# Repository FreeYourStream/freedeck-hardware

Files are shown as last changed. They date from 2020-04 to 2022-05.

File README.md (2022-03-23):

# FreeDeck

## Be careful when printing cases. PCB rev 1.1 - 1.3 has new dimensions. Most cases on thingiverse are still for rev 1.0!

The first cases for Rev 1.1 / 1.2 / 1.3 can be found in the wiki (See link below)

## This Repo contains all the stuff you need to build your own FreeDeck

- [Walkthrough and tutorial](https://youtu.be/-3Zw8hbpVq4) video from Adam Welch
- [Demo Video](https://www.youtube.com/watch?v=_TcliiU2K48) of my first prototype

### [Discord Community](https://discord.gg/sEt2Rrd)

## Description

The FreeDeck aims to be a Free/OpenSource replacement for Elgatos Streamdeck and similar.
It works by creating a config file with the FreeDeck [Configurator](https://fdconfig.freeyourstream.com/), loading it onto an SDCard and inserting it into the FreeDeck. You don't need to install any software and can use it across reboots on Windows, Linux and MacOS. This was my main reason behind this gadget.
This prototype is made from:

- Perfboard
- Arduino Pro Micro (32u4 16mhz 5v)
- 2x 4051 Multiplexer
- 6x ssd1306 OLEDs
- 6x 3x4x2mm SMD buttons
- SPI-SDcard Reader

The Arduino Code can be found [here](https://github.com/koriwi/freedeck-ino)

The Configurator Repo can be found [here](https://github.com/koriwi/freedeck-configurator)

A wiki on how to construct it can be found [here](https://github.com/FreeYourStream/freedeck-wiki/wiki)

Image of first FreeDeck Prototype

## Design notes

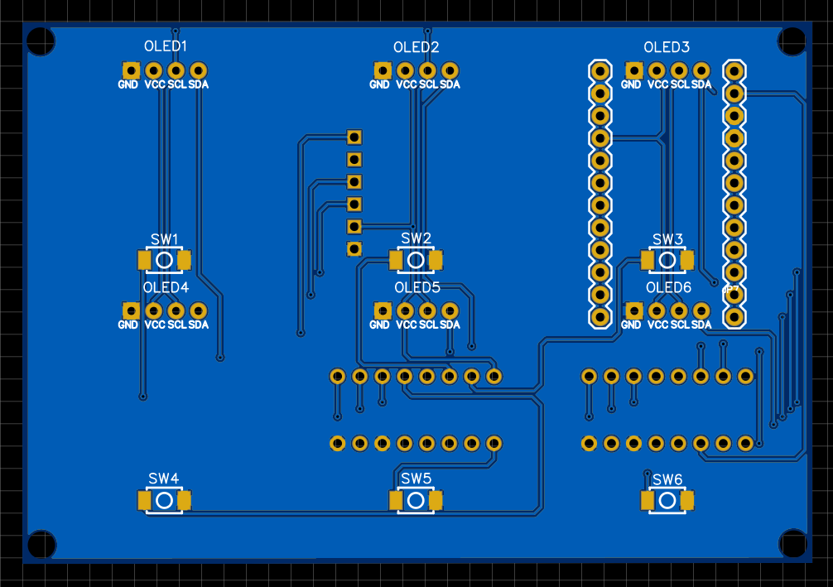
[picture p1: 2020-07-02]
3x2/ThroughHole/FreeDeck_TH_Top.PNG

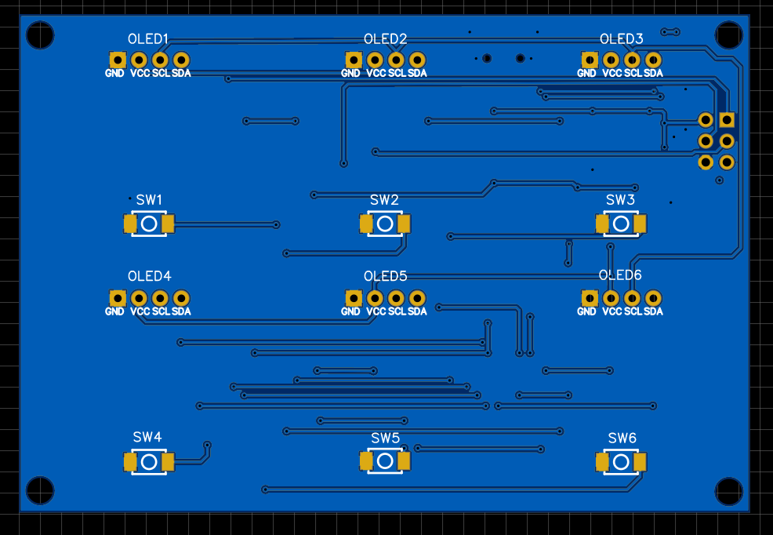
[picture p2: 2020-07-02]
3x2/SurfaceMount/FreeDeck_SMD_Top.PNG

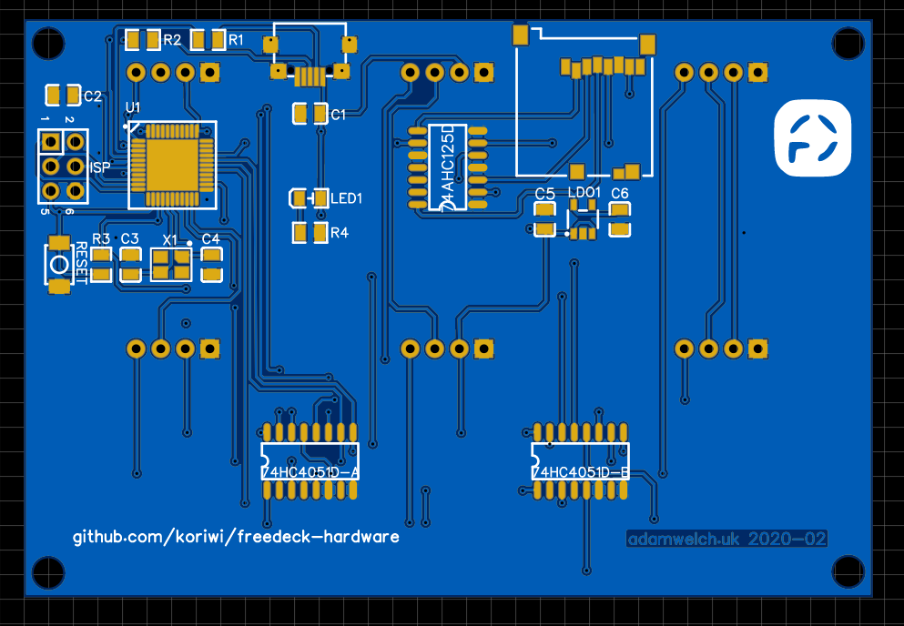
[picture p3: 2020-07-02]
3x2/SurfaceMount/FreeDeck_SMD_Bottom.PNG

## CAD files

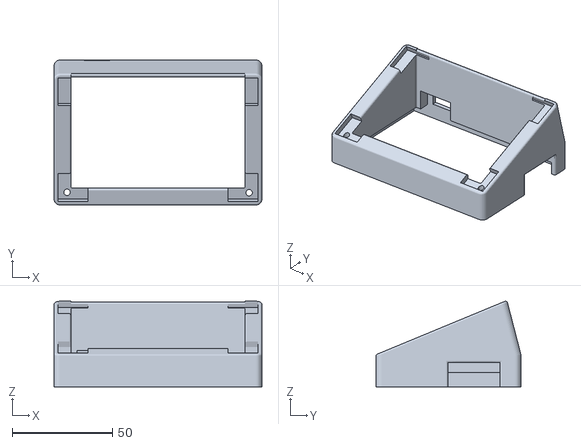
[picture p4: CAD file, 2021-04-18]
3x2/ThroughHole/case/V1.1-V1.2/Freedeck_body_v1.1.stl
103.6 x 72.2 x 42.6

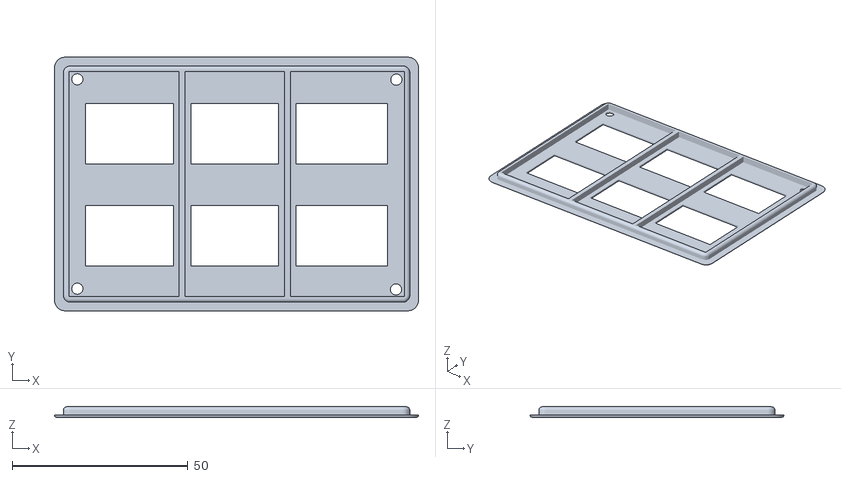
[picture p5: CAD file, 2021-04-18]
3x2/ThroughHole/case/V1.1-V1.2/Freedeck_Lid_v1.1_screw_holes.stl
103.6 x 72.2 x 3.00

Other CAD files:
3x2/ThroughHole/case/V1.1-V1.2/Freedeck_Lid_v1.1_screwless.stl
3x2/ThroughHole/arduino_pro_micro/legacy/case_for_rev_1.1/Freedeck_Lid_v1.1_screwless.stl
3x2/ThroughHole/arduino_pro_micro/legacy/case_for_rev_1.1/Freedeck_Lid_V1.1.f3d
3x2/ThroughHole/arduino_pro_micro/legacy/case_for_rev_1.1/Freedeck_body_v1.1.f3d
3x2/ThroughHole/case/V1.1-V1.2/Freedeck_Lid_V1.1.f3d
3x2/ThroughHole/case/V1.1-V1.2/Freedeck_body_v1.1.f3d
3x2/ThroughHole/case/case_basic_v1.f3z

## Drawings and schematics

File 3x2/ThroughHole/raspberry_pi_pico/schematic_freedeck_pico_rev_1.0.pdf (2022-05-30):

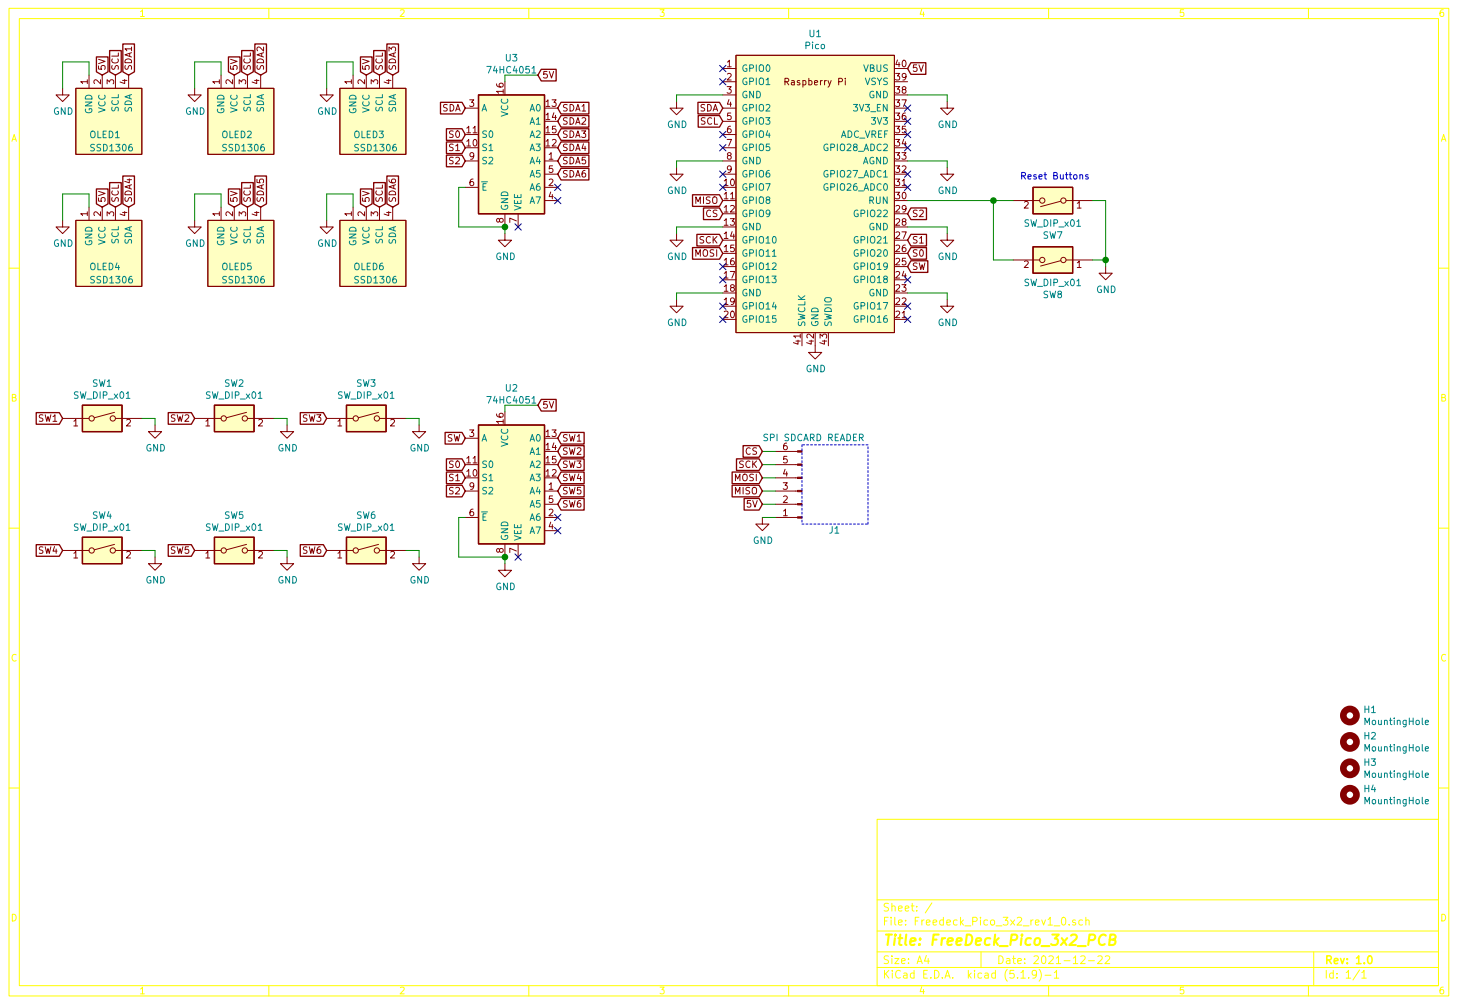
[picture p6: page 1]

J1 SPI SDCARD READER
SCK MISO MOSI CS

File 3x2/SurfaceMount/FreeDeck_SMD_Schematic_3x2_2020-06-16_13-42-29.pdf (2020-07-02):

## SSD1306

## SSD1306

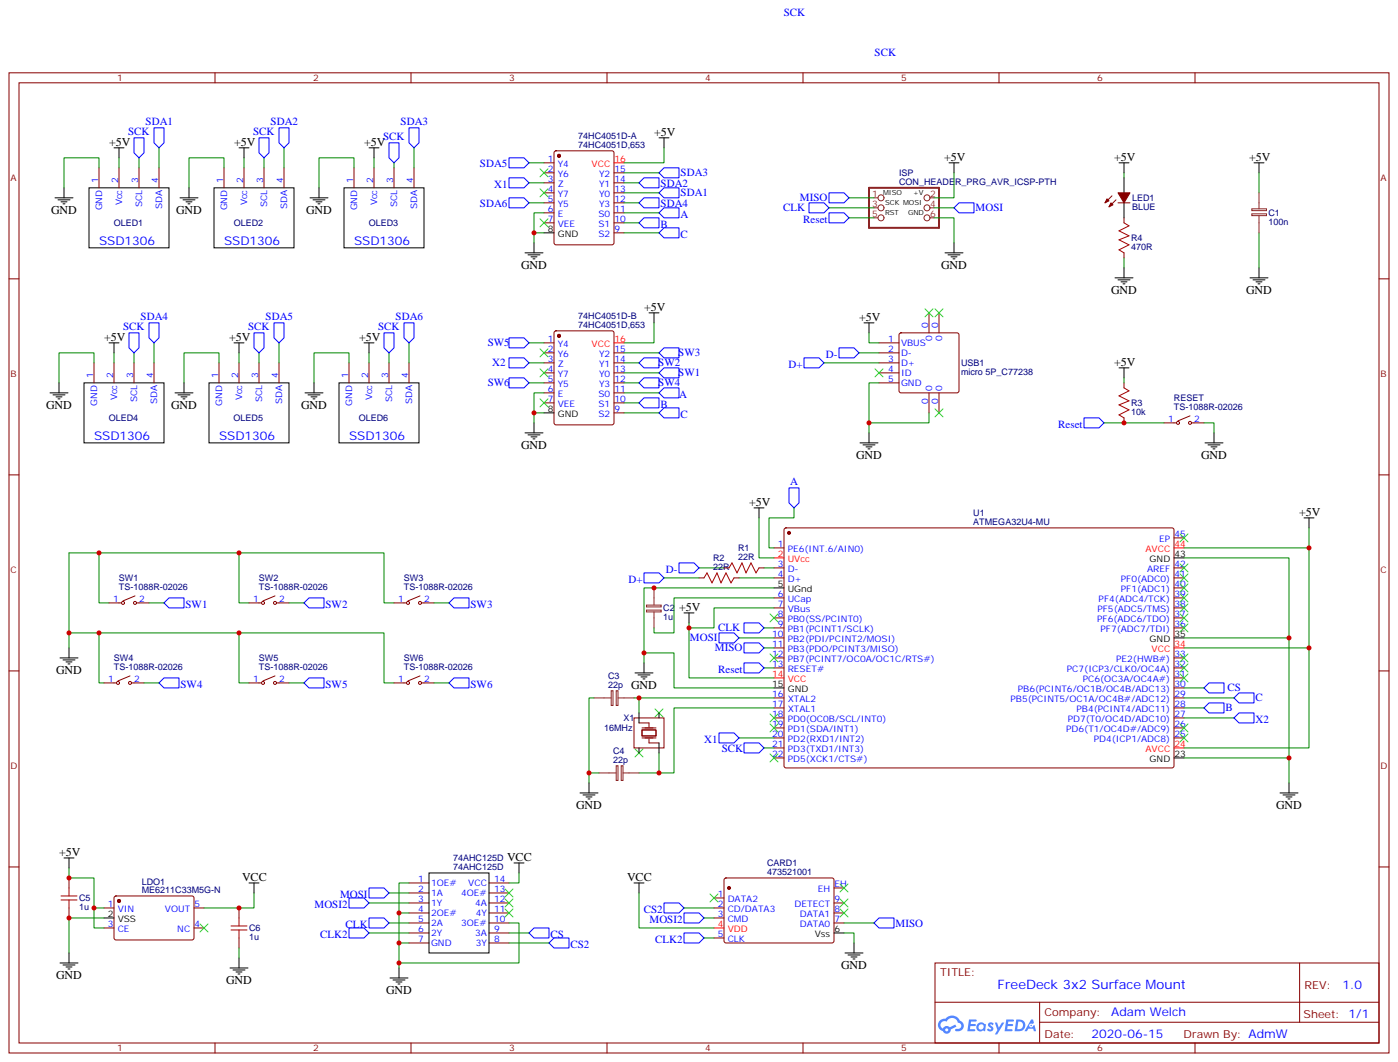
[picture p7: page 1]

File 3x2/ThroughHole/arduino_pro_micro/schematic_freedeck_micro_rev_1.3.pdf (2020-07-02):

## SSD1306

## SSD1306

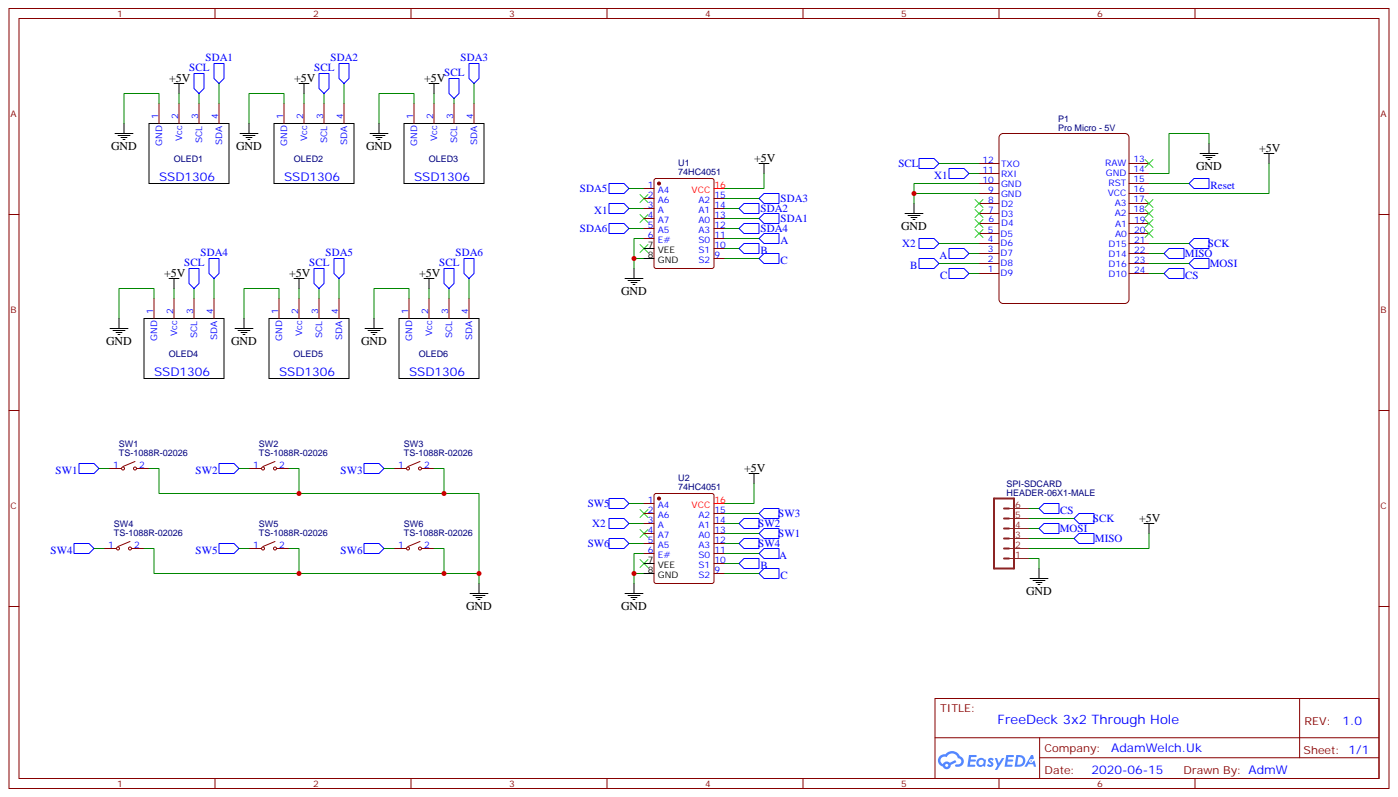
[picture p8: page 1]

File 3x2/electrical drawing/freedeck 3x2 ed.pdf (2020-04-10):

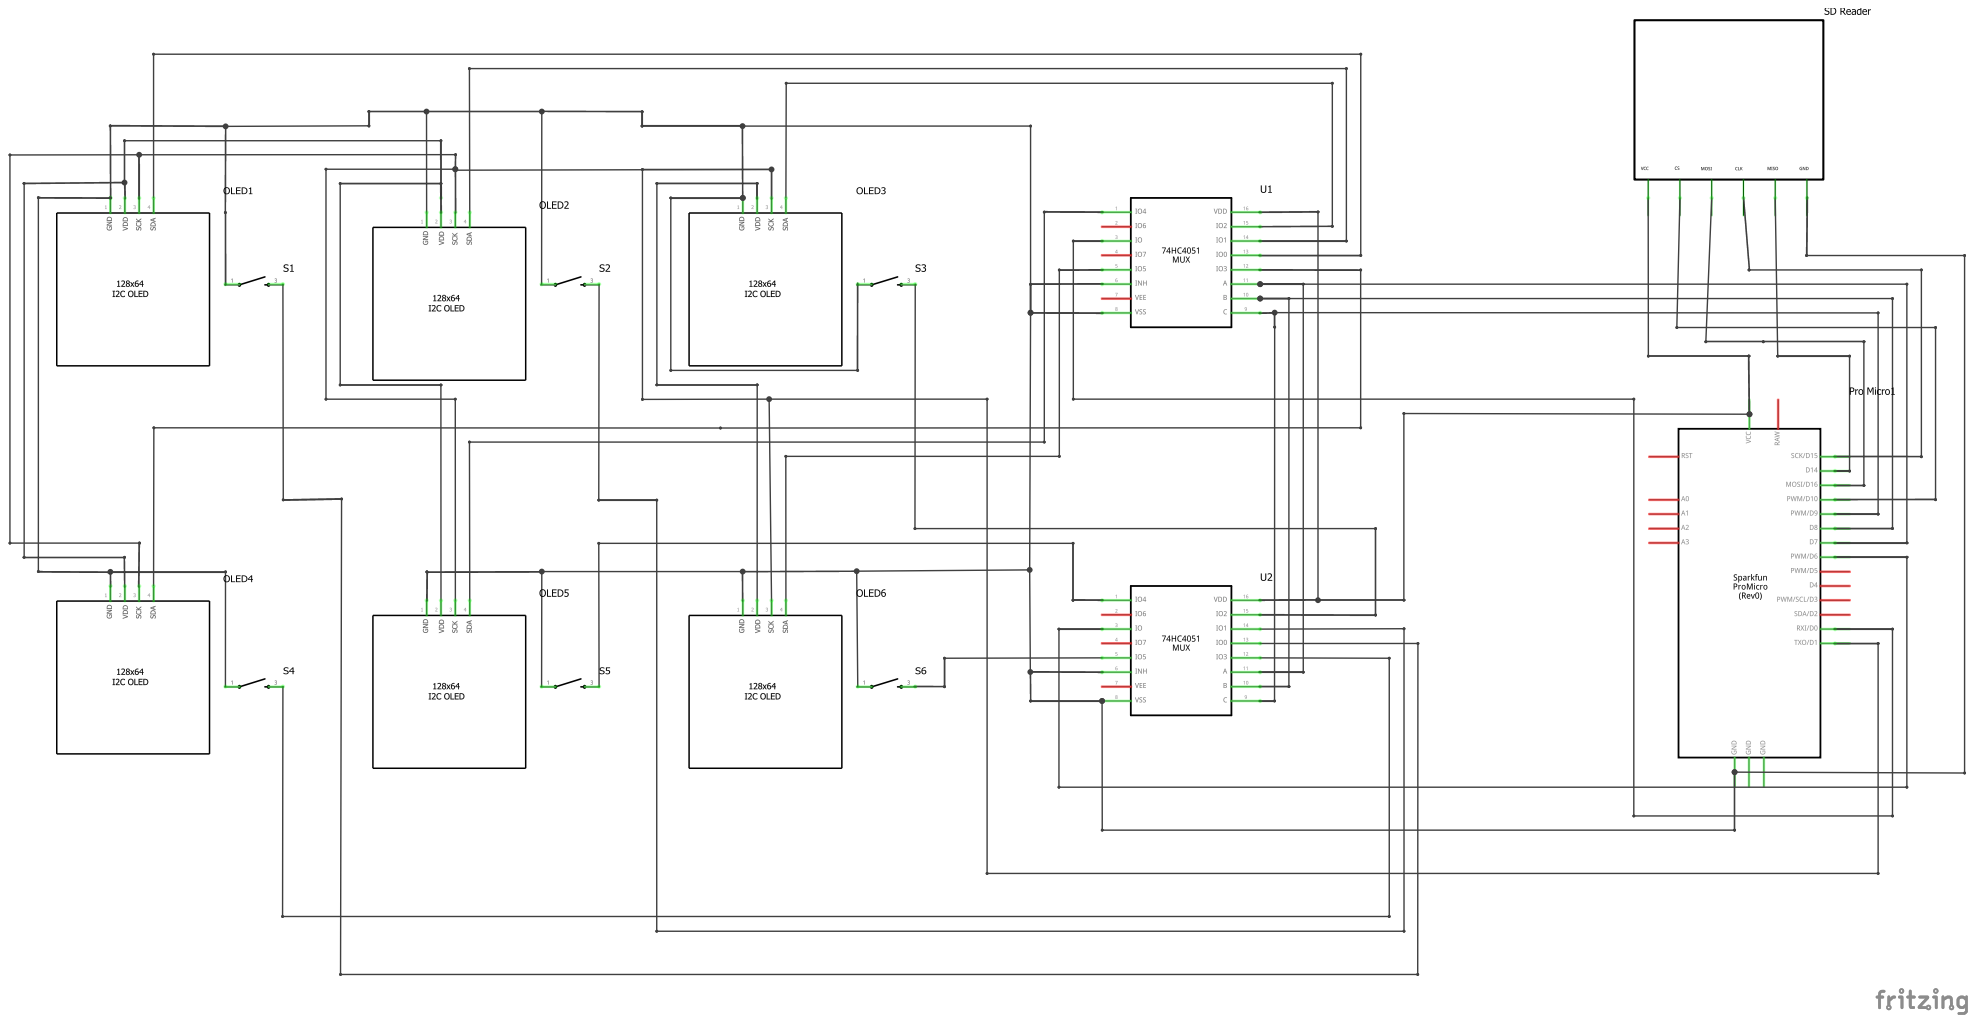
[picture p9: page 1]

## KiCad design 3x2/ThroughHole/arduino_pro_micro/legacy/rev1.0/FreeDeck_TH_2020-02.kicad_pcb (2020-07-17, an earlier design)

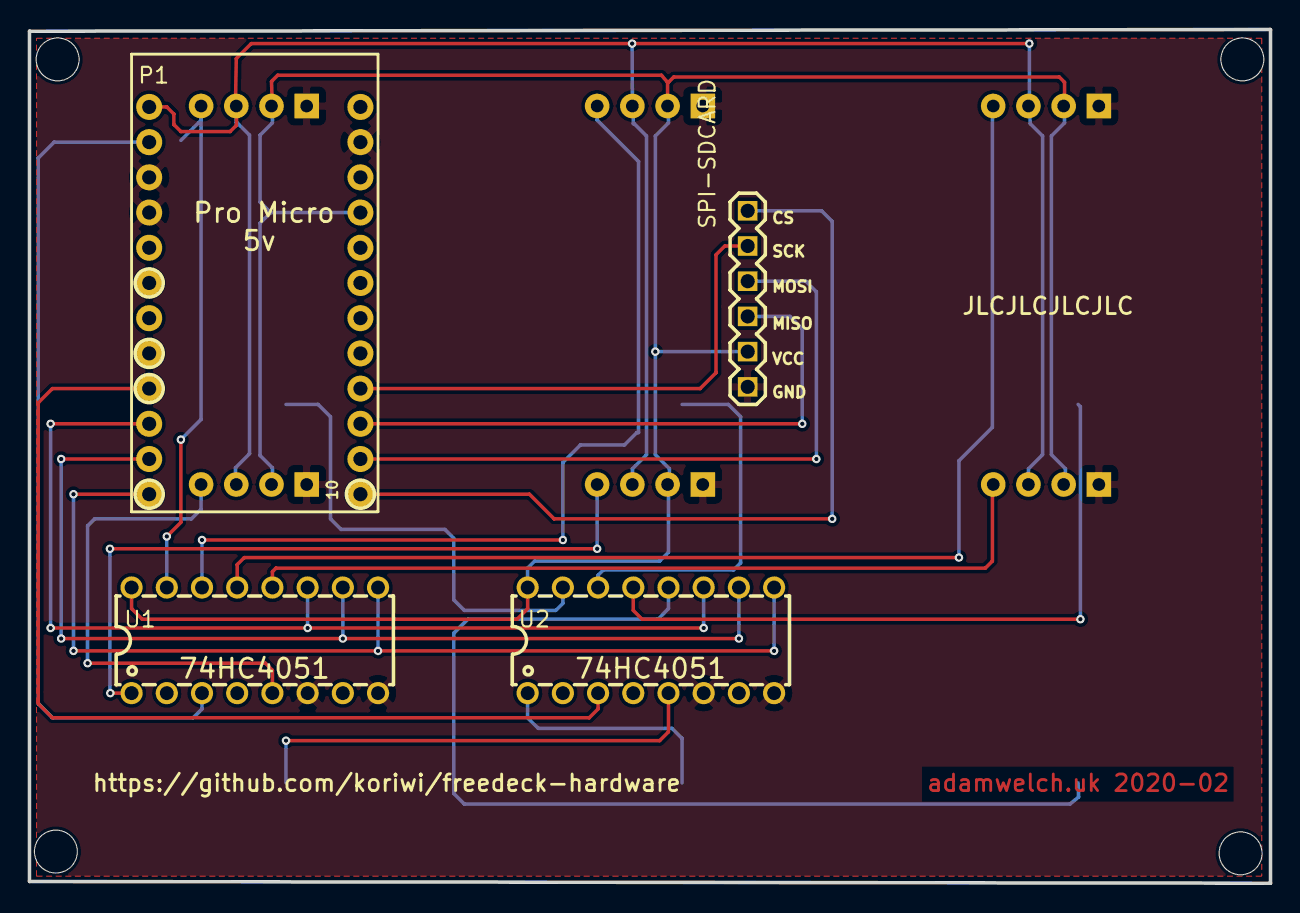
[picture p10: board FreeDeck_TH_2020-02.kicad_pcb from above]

Board: 2 copper layers, 89.5 x 61.6 mm, 16 parts (0 on the bottom side), 24 nets.

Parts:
OLED1, OLED2, OLED3, OLED4, OLED5, OLED6: SDA; SSD1306_ARDUINO
P1: 10; PRO MICRO - 5V
SPI-SDCARD: HEADER-06X1-MALE; 06X1-PTH
SW1, SW2, SW3, SW4, SW5, SW6: TS-1088R-02026; SW-SMD_L3.9-W3.0-P4.45
U1, U2: CD74HC4051E; DIP-16_L20.0-W6.4-P2.54-LS7.6-BL

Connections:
+5V: OLED1.2, OLED2.2, OLED3.2, OLED4.2, OLED5.2, OLED6.2, P1.16, SPI-SDCARD.2, U1.16, U2.16
A: P1.3, U1.11, U2.11
B: P1.2, U1.10, U2.10
C: P1.1, U1.9, U2.9
CS: P1.24, SPI-SDCARD.6
GND: OLED1.1, OLED2.1, OLED3.1, OLED4.1, OLED5.1, OLED6.1, P1.9, P1.10, P1.14, SPI-SDCARD.1, SW1.2, SW2.2, SW3.2, SW4.2, SW5.2, SW6.2, U1.6, U1.8, U2.6, U2.8
MISO: P1.22, SPI-SDCARD.3
MOSI: P1.23, SPI-SDCARD.4
SCK: P1.21, SPI-SDCARD.5
SCL: OLED1.3, OLED2.3, OLED3.3, OLED4.3, OLED5.3, OLED6.3, P1.12
SDA1: OLED1.4, U1.13
SDA2: OLED2.4, U1.14
SDA3: OLED3.4, U1.15
SDA4: OLED4.4, U1.12
SDA5: OLED5.4, U1.1
SDA6: OLED6.4, U1.5
SW1: SW1.1, U2.13
SW2: SW2.1, U2.14
SW3: SW3.1, U2.15
SW4: SW4.1, U2.12
SW5: SW5.1, U2.1
SW6: SW6.1, U2.5
X1: P1.11, U1.3
X2: P1.4, U2.3

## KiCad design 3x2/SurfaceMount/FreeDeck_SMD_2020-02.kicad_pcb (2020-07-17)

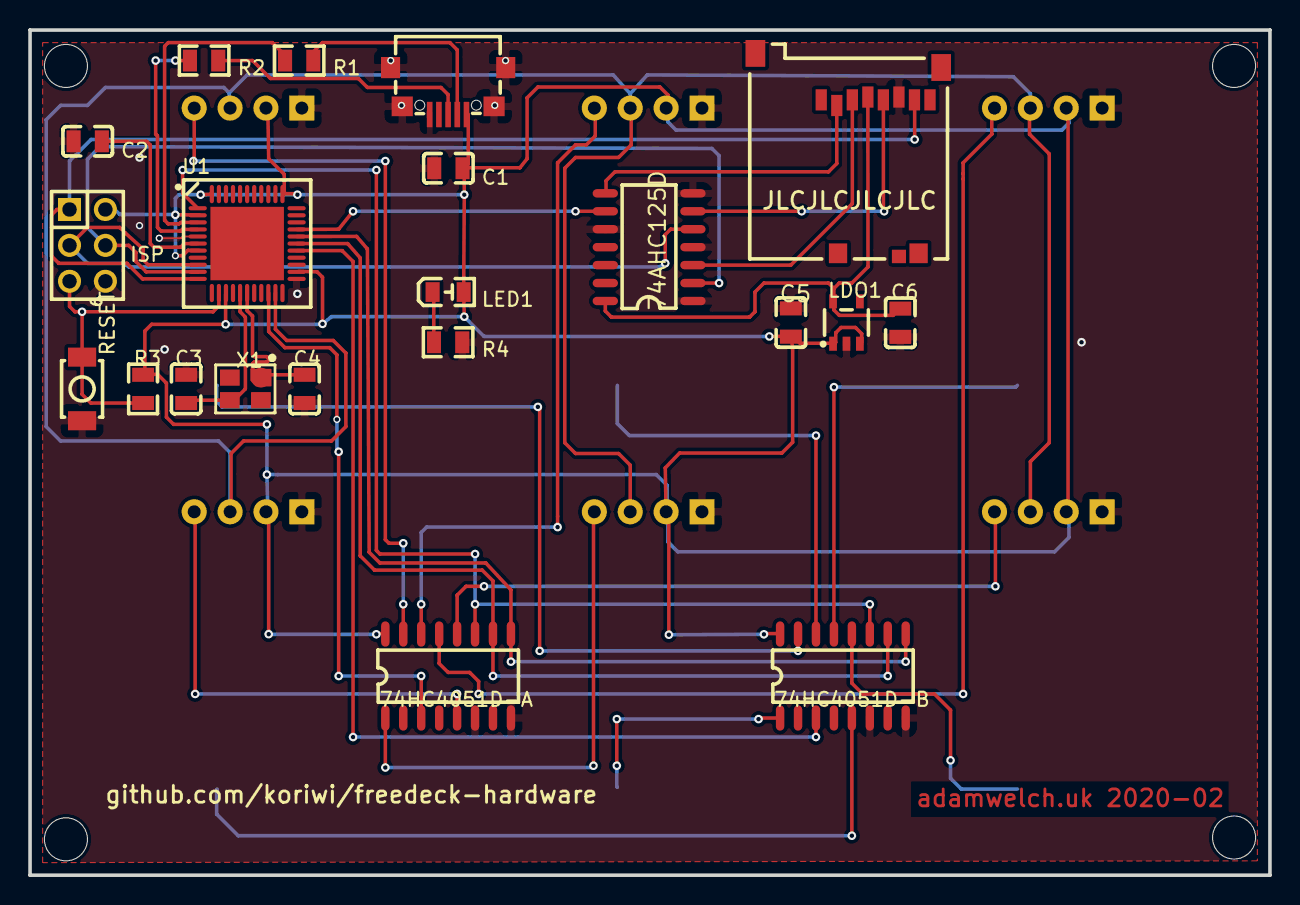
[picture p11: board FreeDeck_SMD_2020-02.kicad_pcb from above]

Board: 2 copper layers, 87.8 x 59.8 mm, 33 parts (0 on the bottom side), 37 nets.

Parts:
74AHC125D: 74AHC125D; SOIC-14_L8.7-W3.9-P1.27-LS6.0-BL
74HC4051D-A, 74HC4051D-B: 74HC4051D,653; SOIC-16_L9.9-W3.9-P1.27-LS6.0-BL
C1: 100n; C0805
C2, C5, C6: 1u; C0805
C3, C4: 22p; C0805
CARD1: 473521001; SD-SMD_SD-47352-101
ISP: 6; HEADER_PRG_2X03
LDO1: ME6211C33M5G-N; SOT-23-5_L3.0-W1.7-P0.95-LS2.8-BL
LED1: BLUE; LED0805-RD
OLED1, OLED2, OLED3, OLED4, OLED5, OLED6: SDA; SSD1306_ARDUINO
R1, R2: 22R; R0805
R3: 10k; R0805
R4: 470R; R0805
RESET: TS-1088R-02026; SW-SMD_L3.9-W3.0-P4.45
SW1, SW2, SW3, SW4, SW5, SW6: TS-1088R-02026; SW-SMD_L3.9-W3.0-P4.45
U1: ATMEGA32U4-MU; VQFN-44_L7.0-W7.0-P0.50-BL-EP5.2
USB1: micro 5P_C77238; MICRO-USB_MICRO-USB-17
X1: 16MHz; OSC-SMD_4P-L3.2-W2.5-BL

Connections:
+5V: 74HC4051D-A.16, 74HC4051D-B.16, C1.1, C5.2, ISP.2, LDO1.1, LDO1.3, LED1.2, OLED1.2, OLED2.2, OLED3.2, OLED4.2, OLED5.2, OLED6.2, R3.1, U1.2, U1.7, U1.14, U1.24, U1.34, U1.44, USB1.1
A: 74HC4051D-A.11, 74HC4051D-B.11, U1.1
B: 74HC4051D-A.10, 74HC4051D-B.10, U1.28
C: 74HC4051D-A.9, 74HC4051D-B.9, U1.29
CLK: 74AHC125D.5, ISP.3, U1.9
CLK2: 74AHC125D.6, CARD1.5
CS: 74AHC125D.9, U1.30
CS2: 74AHC125D.8, CARD1.2
D+: R2.1, USB1.3
D-: R1.1, USB1.2
GND: 74AHC125D.1, 74AHC125D.4, 74AHC125D.7, 74AHC125D.10, 74HC4051D-A.6, 74HC4051D-A.8, 74HC4051D-B.6, 74HC4051D-B.8, C1.2, C2.2, C3.2, C4.2, C5.1, C6.1, CARD1.6, ISP.6, LDO1.2, OLED1.1, OLED2.1, OLED3.1, OLED4.1, OLED5.1, OLED6.1, R4.2, RESET.2, SW1.1, SW2.1, SW3.1, SW4.1, SW5.1, SW6.1, U1.5, U1.15, U1.23, U1.35, U1.43, USB1.0, USB1.5
MISO: CARD1.7, ISP.1, U1.11
MOSI: 74AHC125D.2, ISP.4, U1.10
MOSI2: 74AHC125D.3, CARD1.3
R4_1: LED1.1, R4.1
RESET: ISP.5, R3.2, RESET.1, U1.13
SCK: OLED1.3, OLED2.3, OLED3.3, OLED4.3, OLED5.3, OLED6.3, U1.21
SDA1: 74HC4051D-A.13, OLED1.4
SDA2: 74HC4051D-A.14, OLED2.4
SDA3: 74HC4051D-A.15, OLED3.4
SDA4: 74HC4051D-A.12, OLED4.4
SDA5: 74HC4051D-A.1, OLED5.4
SDA6: 74HC4051D-A.5, OLED6.4
SW1: 74HC4051D-B.13, SW1.2
SW2: 74HC4051D-B.14, SW2.2
SW3: 74HC4051D-B.15, SW3.2
SW4: 74HC4051D-B.12, SW4.2
SW5: 74HC4051D-B.1, SW5.2
SW6: 74HC4051D-B.5, SW6.2
U1_3: R1.2, U1.3
U1_4: R2.2, U1.4
U1_6: C2.1, U1.6
U1_16: C3.1, U1.16, X1.3
U1_17: C4.1, U1.17, X1.1
VCC: 74AHC125D.14, C6.2, CARD1.4, LDO1.5
X1: 74HC4051D-A.3, U1.20
X2: 74HC4051D-B.3, U1.27

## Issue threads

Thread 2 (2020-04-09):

Create gerber files or similar

koriwi, 2020-04-09:
Create above mentioned files for circuit board design to make it possible to order a pcb

koriwi, 2020-04-10:
https://github.com/koriwi/freedeck-hardware/tree/master/3x2/pcb

Closed 2020-04-10.

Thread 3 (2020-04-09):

Create 3d files of the electronics to make it easier to design cases

koriwi, 2020-04-09:

hanswurstgmbh, 2020-04-12:
Someone already made the 3d files
https://grabcad.com/library/arduino-pro-micro-1
https://grabcad.com/library/display-oled-ssd1306-de-0-96-1

koriwi, 2020-07-02:
this issue is relevant again.
we have new (working) PCBs, so the 3d models need to be updated.

koriwi, 2020-07-17:
new pcb files and pcbs are here. i will assign this to myself

koriwi, 2020-08-10:
i'm doing some slight changes to the pcbs right now to avoid the buttons [short cuirciting](https://discordapp.com/channels/699366121593372752/699366419485163660/742492222569840801) the displays.
the pcbs dimensions also change very slightly, so existing 3d cases need to be enlarged @AdamWelchUK

jhaardt, 2021-02-09:
@koriwi
I saw you updated the trough-hole pcb to 1.1, is this the mentioned "slight changes"? If so, I would be willing to design a new case. But it takes some time, just ordered the parts this morning.

koriwi, 2021-02-09:
Yes.

We already have a new case. Soon to be published.
Feel free to design another one :)

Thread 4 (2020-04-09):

rough technical drawing

hanswurstgmbh, 2020-04-09:
It would be nice to have a rough sketch with the distances drawn on it. So a simple rough sketch similar to a technical drawing. So we could create a rough design for a housing in a cad software to be able to print it later directly in 3d.

Thanks!

koriwi, 2020-04-10:
https://github.com/koriwi/freedeck-hardware/blob/master/3x2/pcb/pdf/freedeck%203x2_etch_silk_top.pdf

koriwi, 2020-04-10:
https://github.com/koriwi/freedeck-hardware/blob/master/3x2/pcb/pdf/freedeck%203x2_etch_silk_bottom_mirror.pdf

koriwi, 2020-04-10:
these should be enough :)

koriwi, 2020-04-11:
https://github.com/koriwi/freedeck-hardware/pull/6

koriwi, 2020-04-11:
https://github.com/koriwi/freedeck-hardware/tree/master/3x2/3d/step

hanswurstgmbh, 2020-04-12:
i could not open the stp file and the pdfs do not have the distances, so it will be difficult to make something.
But the case you designed is already very nice

Closed 2020-04-10.

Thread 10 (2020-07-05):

Add BOMs

arturo182, 2020-07-05:
Appreciate the top and bottom images as well as the schematics, but I think a BOM is needed because it's hard to see if the passives are 0806 or 0603 :)

koriwi, 2020-07-10:
after verifying the new pcb's, we will create a BOM

koriwi, 2020-07-17:
the kicad files are online. you can export a BOM from them. i did it in Easy EDA (just zip the kicad file and import it in easy eda).
successfuly exported a bom and a pick and place file :)

Closed 2020-07-17.

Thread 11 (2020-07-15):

Device scaling

DarkLogicX, 2020-07-15:
I was wondering how large could this scale up to?  IE is it possible to have say 9 or more screen/buttons?

I was thinking it might be cool to have one as the max scale that it can go to, or at least as many as the StreamDeck XL.

And would it be possible for there to be a BOM and links to parts for such a scaled up version?

koriwi, 2020-07-17:
this is one for the FAQ
yes, it's possible right now to go up to 16 displays/buttons. arduino code is prepared for this
the configurator right now can only handle 3x2. so any help would be appreciated.

koriwi, 2020-07-17:
BOM, also one for the FAQ. We have the kicad files in the repo. you can zip them and import them to easy_eda where you can export a BOM and  a PickAndPlace file :)

Closed 2020-07-17.

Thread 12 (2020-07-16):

Colour OLED screens?

hazrpg, 2020-07-16:
I just saw your video on YouTube and loved this idea so much. Got me thinking, that I thought, how hard would it be to adapt it for colour OLED screens? Like these ones for example: https://www.ebay.co.uk/itm/0-95-Serial-UART-I2C-SPI-65K-Color-OLED-96x64-Display-Module-for-Arduino-PIC/372240899300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

koriwi, 2020-07-17:
that would be 90$ just for the displays (if you buy them from your link)

kriFPV, 2020-07-18:
I had a similar idea but these LCD screens would be MUCH cheaper than oleds. https://www.aliexpress.com/item/32918394604.html

koriwi, 2020-08-10:
please reopen if you have more information and check out #16

Closed 2020-08-10.

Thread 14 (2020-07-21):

SMD BOM

TheFrenchSpy, 2020-07-21:
Hi, is it possible to get a BOM for the SMD version of the board?

carlfugate, 2020-07-24:
I'm looking for the SMD BOM as well.

koriwi, 2020-07-24:
from the easyeda, kicad files, you can export a BOM :)

carlfugate, 2020-07-24:
Thanks @koriwi.  Here is an export.
[BOM_FreeDeck 2020-02_2020-07-24_13-12-55.pdf](https://github.com/koriwi/freedeck-hardware/files/4973641/BOM_FreeDeck.2020-02_2020-07-24_13-12-55.pdf)

Closed 2020-08-10.

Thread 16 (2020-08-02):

Using colour LCD screens?

kriFPV, 2020-08-02:
https://www.aliexpress.com/item/32918394604.html
These screens cost about the same but they can display colours. Would it be possible to use them instead?

koriwi, 2020-08-10:
i think the arduino does not have enough horsepower to refresh colored screens fast enough.
feel free to reopen the issue if you have more information :)

seanspotatobusiness, 2021-03-19:
What about the stm32f103c8t6 (aka blue pill) - does that not have enough processing power?

Closed 2020-08-10.

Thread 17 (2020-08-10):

bigger version(s)

koriwi, 2020-08-10:
we are developing a concept for a 4x3 version (and similar) right now
We still need:
- through hole pcb files
- SMD pcb files
- 3d files
- cases designed around above mentioned 3d files

GitOeli, 2020-10-16:
Hello,
are you still looking for help on this one? I would really love to see a bigger Version of this awesome project! I have basic skills in PCB Design (mostly Eagle and KiCad, but I would be open to learn an new software in the process). Additionally I have experience with 3D Modelling in Solidworks, but I currently do not have access to this software. Maybe I can provide some help to make this one happen!

koriwi, 2020-10-18:
Hi. We just made a new PCB revision for the 3x2 version. If it proves to be a good design (including cases) you could base the 4x3 design on this new PCB and case (case follows soon)

GitOeli, 2020-10-19:
Hi, sounds good. Is there an ETA for the new PCB Design?
I played a bit around in easyEDA because it seemed to be the software that was used to create the PCB that is currently available. Seems to be the easiest PCB design software I've used so far. So if the new version is created in easyEDA aswell I could get started relatively quickly.
What Software are you using for the case 3D files?

koriwi, 2020-10-23:
The PCBs are on their way right now. i expect them to arrive latest in a few days. if i think it's good, i will update the pcb design in github. then you can easily start with a bigger version in easyEDA.

First case i wanted to design in fusion360, my default software, but recently i switched to openSCAD (because linux and so on)

GitOeli, 2020-10-25:
I am looking forward to the new design! How will the additional displays and switches handled on the arduino side? Two more signals (i.e. X3 and X4) and two more 4051s?

koriwi, 2020-11-01:
The new pcbs should arrive on monday!
For designs above 8 display i intend to use the widely and cheaply availabe 4067 16 channel multiplexer.

GitOeli, 2020-11-04:
Ah okay. So there will be only need for one more signal (D) between the ICs and the Arduino.
That's good to hear. I am looking forward to getting started!

ZeddBlock, 2020-12-06:
Hi, very nice design, and awesome work ! Firstly, forgive my english (I'm french).
I plan to make this for some time now, but I would like a 4x3 or 5x3 or 4.

My knowledges aren't enough to do it by myself. So I guess I'll wait your new one.

Again thanks a lot for your work !

GitOeli, 2020-12-07:
I've created a PCB for a 4x3 Version, but I haven't tested it yet. I am not sure when I will be able to test this design and there isn't a case yet.
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

ZeddBlock, 2020-12-07:
Ho, super nice !
But, for this design, you site to configure it won't work  ? And the arduino code would be very different ?

GitOeli, 2020-12-07:
As far as I can tell the arduino code is ready for more displays. Two minor changes in the settings.h file are needed and that's it. I don't know about the state of the configurator.

feedtechmobile, 2020-12-16:
Is it possible to update to receive colored icons? I'm looking for acrylic protectors like buttons for OLED screens for fear of compromising the OLED display @koriwi

koriwi, 2020-12-16:
Configurator needs to be updated for 4x3. It's not that much, but i have no bigger version for testing.

Color is not possible right now. Arduino has not enough processing power to refresh it fast enough

GitOeli, 2020-12-17:
I could provide the files for the 4x3 DIP Version if someone would want to test it. I will move at some uncertain point in the near future so I can't order stuff that will take some time to arrive. So I dont know when I will be able to test this design. But first I will post it in the discord to check for errors that I may have missed. I moved the additional signal for the multiplexers from 10 to 5 because 10 was already occupied with the SD Card and it was easier to route this way. I hope that doesn't cause any issues.

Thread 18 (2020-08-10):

3rd party input

koriwi, 2020-08-10:
exposing some pins which can be used to connect buttons, pedals, etc.
https://de.aliexpress.com/item/4000956129652.html
6.35mm/3.5mm (head phone) jack would be nice as a connector

legomannetje, 2023-06-25:
I'm going to pick this up in the PCB varient im currently building, would need help with the support on the configurator side of the project

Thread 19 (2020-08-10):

integrated rotary encoder(s)

koriwi, 2020-08-10:
have a rotary encoder/joystick in a corner which can be used to scrub through a timeline for example

koriwi, 2022-05-01:
final version should something like this. https://www.youtube.com/watch?v=NPfaLKKsf_Q

legomannetje, 2023-06-25:
I'm going to pick this up in the PCB varient im currently building, would need help with the support on the configurator side of the project

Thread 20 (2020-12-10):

Suggestion add 240*240 1.3" display

Brun0kill, 2020-12-10:
Hi, I have a sugestion to replace the ssd1306 OLEDs with a 8/7 pin square color screen, to make more similar than StreamDeck

koriwi, 2021-05-19:
This would be nice, but i dont think we have the horse power right now with our current hardware.

Closed 2021-05-19.

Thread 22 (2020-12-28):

Arduino

chicaoo, 2020-12-28:
Hi! good night
can i do with Arduino uno?

humphrey13, 2021-01-23:
what do you what to do?

legomannetje, 2021-04-20:
Hey @chicaoo, technically yes. But its far from easy. You need to reflash some of the chips on de arduino Uno board, and since this is a quite difficult i would not recommend it. If done wrong it can and will destroy your Uno. The easiest way is to get a cheap pro micro from China.

If you want to try, here is a guide on how to reflash your uno: https://github.com/NicoHood/HoodLoader2/wiki

Closed 2021-05-19.

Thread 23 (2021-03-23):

Nothing displayed on screen

HarsiFPV, 2021-03-23:
Using all the components listed, I finished building it and when I plug it in after puting in the SD card containing the config file, the screens light up bright but do not display any image contained in the SD card. Using the serial function in the configurator doesn't help.
If you have any idea of what could be causing the issue feel free to tell me.
Thanks :)

Gregor-Davies, 2021-03-23:
Hey!
It would be helpful if you provided a picture of your wiring to make sure everything is connected properly.

HarsiFPV, 2021-03-23:
Hey ! My bad for not saying this but I am using the pcb that Adam Welch provides in his video. [
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

](url)

Gregor-Davies, 2021-03-24:
Did/does the Arduino work when not attached to the pcb? The pins on the Arduino might need a bit more solder.

HarsiFPV, 2021-03-24:
Yes I flashed the arduino with the sketch before soldering it. I will try to add a little bit more solder. I'll keep you in touch thanks :)

HarsiFPV, 2021-03-24:
So I wen't ahead and reflowed solder on every pin of the board, and I am still facing the same issue :(

Gregor-Davies, 2021-03-24:
In that case there's something wrong in the pcb try going around on the pcb with a multimeter.

legomannetje, 2021-04-20:
Hey HarsiFPV,

If you still have this issue, please visit our discord! [Click here to join](https://discord.gg/sEt2Rrd)

koriwi, 2021-05-19:
Feel free to reopen or comment your solution. will close this ticket now :)

Closed 2021-05-19.

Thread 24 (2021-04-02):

Feature suggestion: support 0.49" OLEDs

Tirpitz93, 2021-04-02:
This would allow a higher density of macros per board.
OLEDs I am referring to are similar to these: https://www.smart-prototyping.com/0-49-OLED-display-IIC-6432

Gregor-Davies, 2021-04-21:
It seems like a good idea and very easy to implement since I believe they use the same connectors so it would only require a very simple pcb revision.

👍

koriwi, 2021-05-19:
if you handsolder it, it should work out of the box with the firmware :)
We have plans to design other sizes and form factors. But there is no spare time for this atm. But feel free to make a pcb based on ours. I will happily merge it :)

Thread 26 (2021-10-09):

Hardware Suggestion: MCP23017 & TCA9548A

abrilevskiy, 2021-10-09:
I propose to use MCP23017/MCP23008 - an I2C port extender to handle button press via interrupts
and use TCA9548A (or similar) as an OLED screen multiplexer.

koriwi, 2021-11-01:
Can you elaborate what improvements we will get from that? because the i2c multiplexer is much more expensive and i dont know if it will be compatible with the i2c bitbanging we are using.

Also i dont think we can use the i2c port extender with the bitbanging or we would have to implement a minimum lib by ourselves.

Also the normal analog multiplexers work and are much cheaper and easier to get around the world

Closed 2022-05-01.

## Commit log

2020-04-10 first horrible version
    cant upload pcb file right now. fritzing keeps crashing. help appreciated
2020-04-11 move displays
    moves display by 0.6mm
    [pcb 3d.step]
2020-04-11 added first case prototype
    [case_base.stl, case_lid.stl]
2020-06-17 New PCB designs
2020-07-02 remove legacy files
    [case_base.stl, case_lid.stl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]
2020-07-17 KiCAD PCB File
    [FreeDeck_SMD_2020-02.kicad_pcb]
2020-11-29 adds rev 1.1 pcb files
2021-03-03 reorganize old and new pcbs
    [FreeDeck_TH_2020-02.kicad_pcb]
2021-04-18 [Case] Added case for PCB v1.1 & v1.2
    [Freedeck_Lid_V1.1.f3d, Freedeck_Lid_v1.1_screw_holes.stl, Freedeck_Lid_v1.1_screwless.stl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]
2022-03-23 Added PCB Rev1.3 (#27)
    * Added file for 1.3
    * Updated README.md
    * Added changelog
2022-05-30 reorganize and add pi pico+case (#29)
    [FreeDeck_TH_2020-02.kicad_pcb, Freedeck_Lid_V1.1.f3d, Freedeck_Lid_v1.1_screw_holes.stl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]
